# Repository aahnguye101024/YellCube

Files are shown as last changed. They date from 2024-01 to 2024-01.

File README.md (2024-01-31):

# YellCube
This device is intended to connect stream audio and flash lights representative of the audio. This device streams songs that are uploaded to another repo (https://github.com/aahnguye101024/ESP32Audio). This project was also a way for me to test out the 3D printer I just bought in a fun way. With an ESP32 pico d4 with an antenna, onboard leds, a dedicated SK6812 LED board, an audio amplifier, an onboard lipo with supported charging and uploading straight to the pico D4, this board can be easily programmed and adapted to any of your speaker and lights project needs.

# Main Board
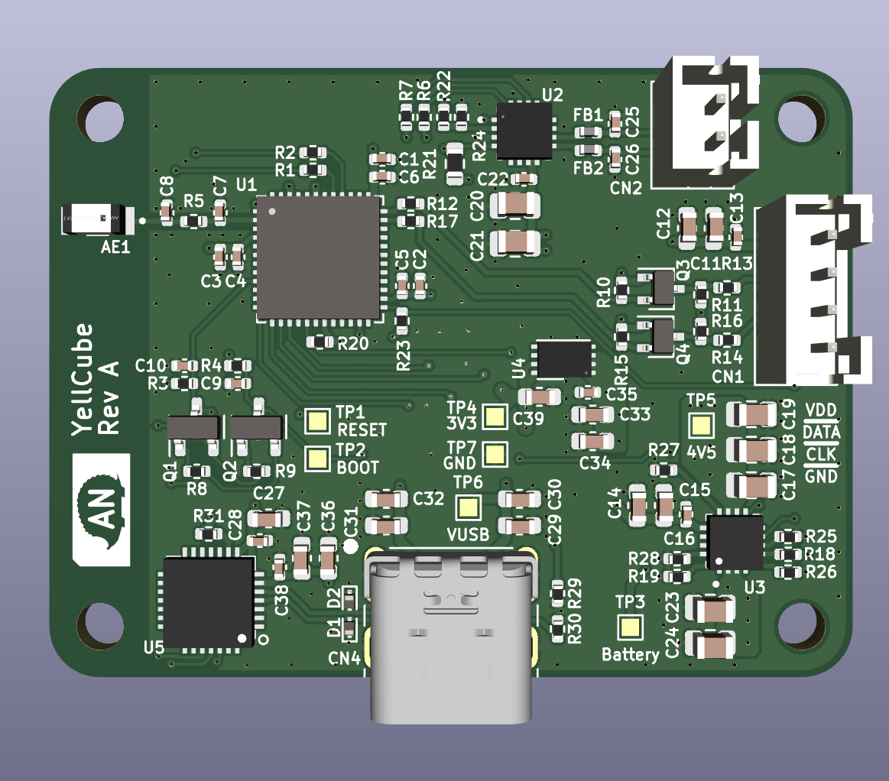
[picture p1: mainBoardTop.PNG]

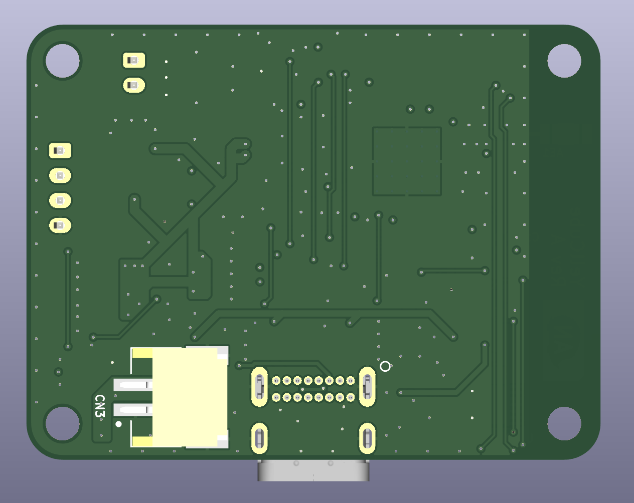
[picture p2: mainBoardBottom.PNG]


# Lights Board
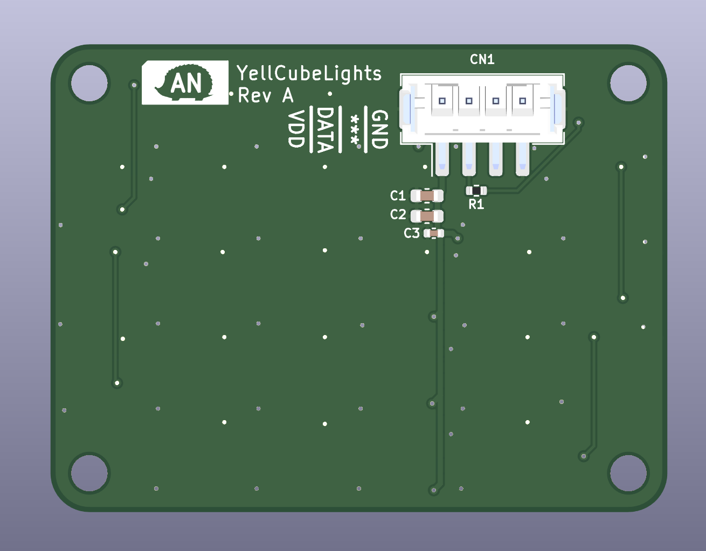
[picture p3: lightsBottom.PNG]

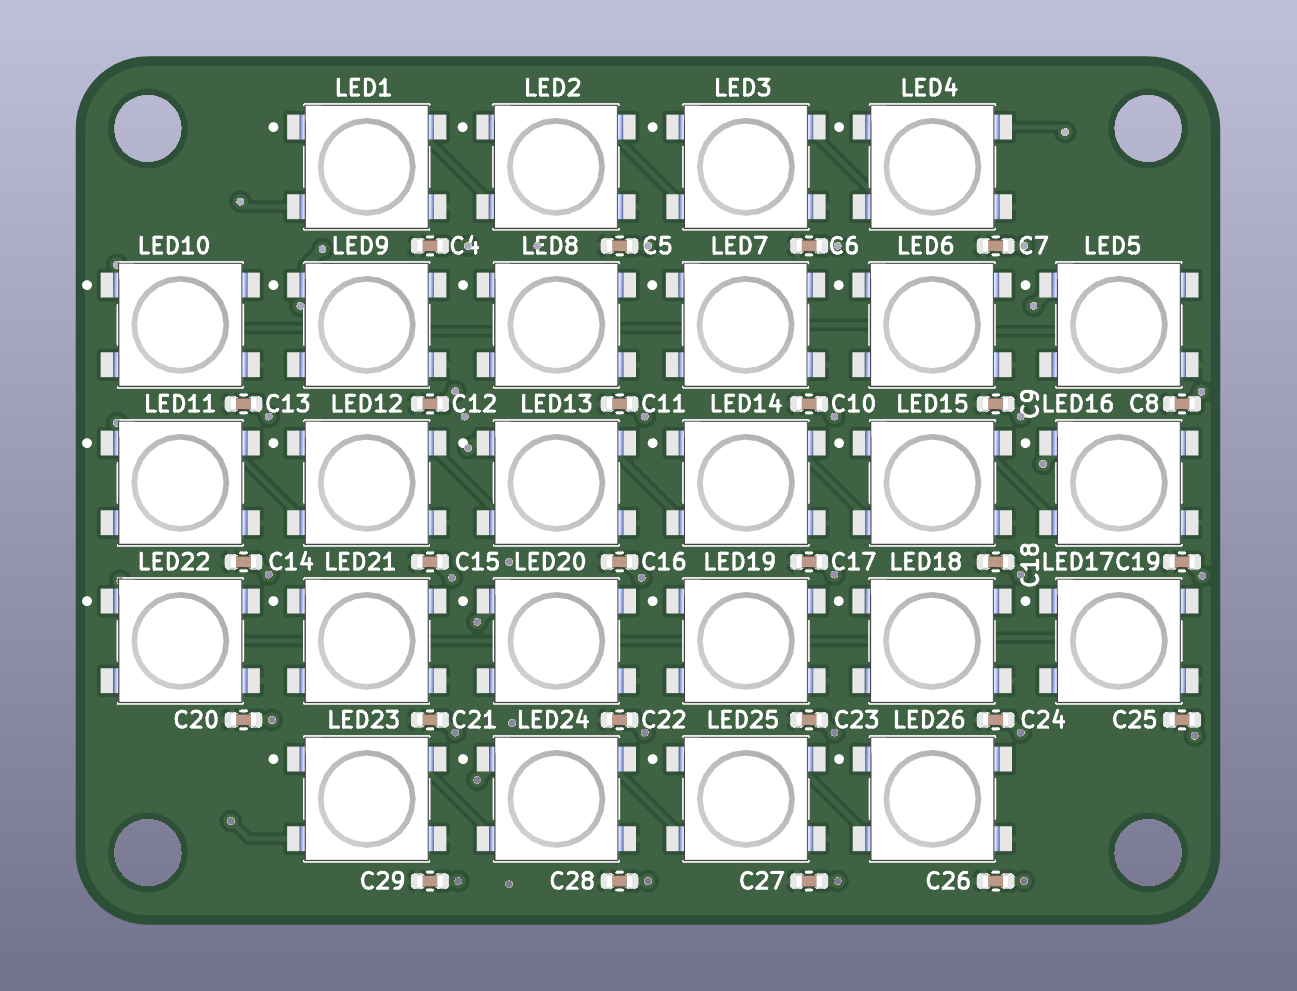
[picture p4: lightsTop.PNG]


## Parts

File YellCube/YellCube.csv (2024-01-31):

Source: | C:\Users\AaronN\Desktop\Personal\PersonalProjects\YellCube\YellCube\YellCube.kicad_sch
Date: | 4/16/2022 9:40:53 PM
Tool: | Eeschema (6.0.0)
Generator: | C:\Program Files\KiCad\bin\scripting\plugins/AaronsFavoriteBOMScript.py
Component Count: | 90
Ref | Qnty | Value | Cmp name | Description | Manufacturer | Part Number
AE1, | 1 | AMCA31-2R450G-S1F-T3 | AMCA31-2R450G-S1F-T3 | RF ANT 2.4GHZ CHIP SOLDER SMD | Personal | 535-14095-1-ND
C1, C2, C3, C10, | 4 | 1uF | 1uF | CAP CER 1UF 10V X5R 0402 | Samsung Electro-Mechanics | 1276-1076-1-ND
C4, C5, C6, C9, C13, C16, C22, C28, C35, C38, | 10 | 0.1uF | 0.1uF | CAP CER 0.1UF 25V X5R 0402 | Samsung Electro-Mechanics | 1276-1043-1-ND
C11, C12, C33, C34, C39, | 5 | 4.7uF | 4.7uF | CAP CER 4.7UF 16V X5R 0603 | Samsung Electro-Mechanics | 1276-1784-1-ND
C14, C15, C27, C29, C30, C31, C32, C36, C37, | 9 | 2.2uF | 2.2uF | CAP CER 2.2UF 10V X5R 0603 | Samsung Electro-Mechanics | 1276-1085-1-ND
C17, C18, C19, C20, C21, C23, C24, | 7 | 10uF | 10uF | CAP CER 10UF 16V X5R 0805 | Samsung Electro-Mechanics | 1276-2893-1-ND
C25, C26, | 2 | 220pF | 220pF | CAP CER 220PF 50V X7R 0402 | YAGEO | 311-1035-1-ND
CN1, | 1 | B4B-PH-K-S(LF)(SN) | B4B-PH-K-S(LF)(SN) | JST PH CONN HEADER VERT 4POS 2MM | JST Sales America Inc. | 455-1706-ND
CN2, | 1 | B2B-PH-K-S(LF)(SN) | B2B-PH-K-S(LF)(SN) | JST PH CONN HEADER VERT 2POS 2MM | JST Sales America Inc. | 455-1704-ND
CN3, | 1 | S2B-PH-SM4-TB(LF)(SN) | S2B-PH-SM4-TB(LF)(SN) | JST PH R/A CONN HEADER SMD R/A 2POS 2MM | JST Sales America Inc. | 455-1749-1-ND
CN4, | 1 | 2137160001 | 2137160001 | CONN RCPT USB2.0 TYPE C 24POS RA | Personal | 900-2137160001CT-ND
D1, D2, | 2 | ESD7951ST5G | ESD7951ST5G | TVS DIODE 5VWM 12.9VC SOD923 | onsemi | ESD7951ST5GOSCT-ND
FB1, FB2, | 2 | BLM15PX601SN1D | BLM15PX601SN1D | FERRITE BEAD 600 OHM 0402 1LN | Murata Electronics | 490-9657-1-ND
H1, H2, H3, H4, | 4 | MountingHole | MountingHole | Mounting Hole without connection
Q1, Q2, | 2 | MMBT3904 | MMBT3904 | JLCPCB 0.2W 0.2A NPN 40V SOT-23(SOT-23-3) Bipolar Transistors - BJT ROHS | Changjiang Electronics Tech (CJ) | C20526
Q3, Q4, | 2 | BSS138W-7-F | BSS138W-7-F | 50V Vds, 0.2A Id, N-Channel MOSFET, SOT-323 | Personal | BSS138W-FDICT-ND
R1, R2, R5, R12, R13, R14, R17, | 7 | 0 | 0 | RES 0 OHM JUMPER 1/16W 0402 | Stackpole Electronics Inc | RMCF0402ZT0R00CT-ND
R3, R8, R9, R10, R11, R15, R16, R18, R19, R20, R23, R25, R26, R31, | 14 | 10k | 10k | RES 10K OHM 1% 1/16W 0402 | Stackpole Electronics Inc | RMCF0402FT10K0CT-ND
R4, R28, | 2 | 4.7k | 4.7k | RES 4.7K OHM 1% 1/16W 0402 | Stackpole Electronics Inc | RMCF0402FT4K70CT-ND
R6, R7, | 2 | 33 | 33 | RES 33 OHM 1% 1/16W 0402 | YAGEO | 311-33.0LRCT-ND
R21, | 1 | 680k | 680k | RES 680K OHM 1% 1/10W 0603 | Stackpole Electronics Inc | RMCF0603FT680KCT-ND
R22, R24, | 2 | 100k | 100k | RES SMD 100 KOHM 1% 1/16W 0402 | Delta Electronics/Cyntec | 2037-PFR05S-104-FNHCT-ND
R27, | 1 | 3.09k | 3.09k | RES 3.09K OHM 1% 1/16W 0402 | Stackpole Electronics Inc | RMCF0402FT3K09CT-ND
R29, R30, | 2 | 5.1k | 5.1k | RES 5.1K OHM 1% 1/16W 0402 | YAGEO | 311-5.10KLRCT-ND
U1, | 1 | ESP32-PICO-D4 | ESP32-PICO-D4 |  | Personal | 1904-1029-1-ND
U2, | 1 | MAX98357AETE+T | MAX98357AETE+T | JLCPCB IC AMP CLASS D MONO 3.2W 16TQFN | Analog Devices Inc./Maxim Integrated | MAX98357AETE+TCT-ND
U3, | 1 | BQ24232HARGTR | BQ24232HARGTR | IC BATT CHG LI-ION 1CELL 16QFN | Texas Instruments | 296-49554-1-ND
U4, | 1 | MCP1725T-3302E/MC | MCP1725T-3302E{slash}MC | IC REG LINEAR 3.3V 500MA 8DFN | Microchip Technology | MCP1725T-3302E/MCCT-ND
U5, | 1 | CP2102-GMR | CP2102-GMR | JLCPCB IC USB-TO-UART BRIDGE 28VQFN | Personal | IC USB-TO-UART BRIDGE 28VQFN

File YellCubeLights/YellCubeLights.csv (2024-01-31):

Source: | C:\Users\AaronN\Desktop\Personal\PersonalProjects\YellCube\YellCubeLights\YellCubeLights.kicad_sch
Date: | 4/16/2022 9:31:28 PM
Tool: | Eeschema (6.0.0)
Generator: | C:\Program Files\KiCad\bin\scripting\plugins/AaronsFavoriteBOMScript.py
Component Count: | 61
Ref | Qnty | Value | Cmp name | Description | Manufacturer | Part Number
C1, C2, | 2 | 2.2uF | 2.2uF | CAP CER 2.2UF 10V X5R 0603 | Samsung Electro-Mechanics | 1276-1085-1-ND
C3, | 1 | 0.1uF | 0.1uF | CAP CER 0.1UF 25V X5R 0402 | Samsung Electro-Mechanics | 1276-1043-1-ND
C4, C5, C6, C7, C8, C9, C10, C11, C12, C13, C14, C15, C16, C17, C18, C19, C20, C21, C22, C23, C24, C25, C26, C27, C28, C29, | 26 | 1uF | 1uF | CAP CER 1UF 10V X5R 0402 | Samsung Electro-Mechanics | 1276-1076-1-ND
CN1, | 1 | B4B-PH-SM4-TBT(LF)(SN) | B4B-PH-SM4-TBT(LF)(SN) | JST PH CONN HEADER SMD 4POS 2MM | JST Sales America Inc. | 455-2873-1-ND
H1, H2, H3, H4, | 4 | MountingHole | MountingHole | Mounting Hole without connection
LED1, LED2, LED3, LED4, LED5, LED6, LED7, LED8, LED9, LED10, LED11, LED12, LED13, LED14, LED15, LED16, LED17, LED18, LED19, LED20, LED21, LED22, LED23, LED24, LED25, LED26, | 26 | SK6812 | SK6812 | RGBW LED | Pololu | N/A
R1, | 1 | 33 | 33 | RES 33 OHM 1% 1/16W 0402 | YAGEO | 311-33.0LRCT-ND

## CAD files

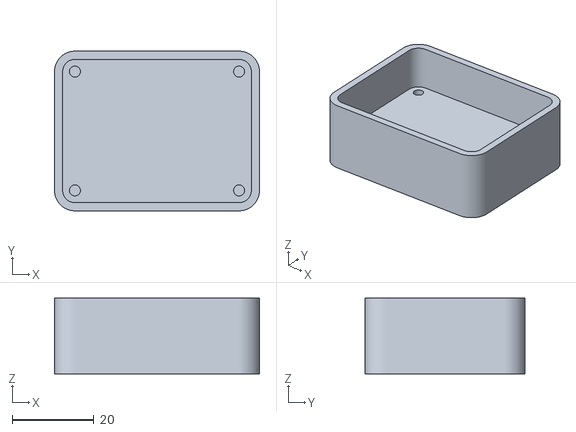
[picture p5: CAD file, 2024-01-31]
mechanical/stl/BottomCase v3.stl
50.2 x 39.1 x 18.6

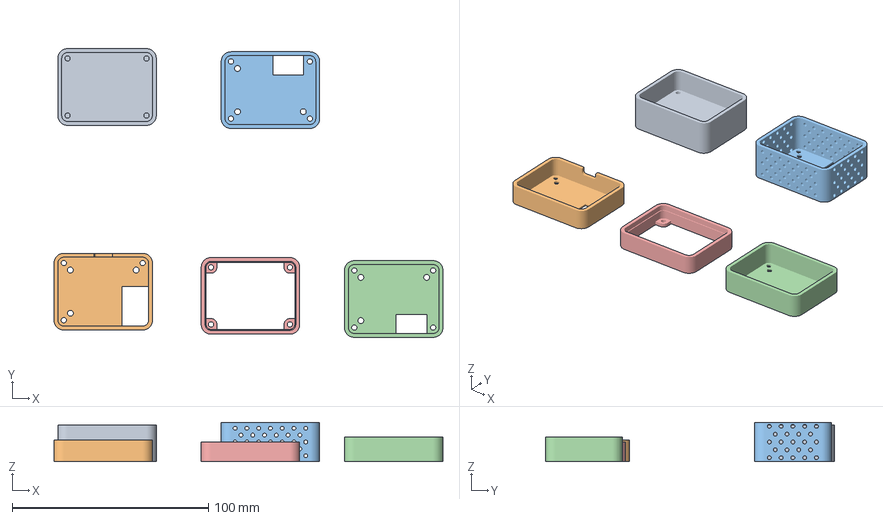
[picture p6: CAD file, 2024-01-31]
mechanical/YellCube.3mf
198.2 x 147.1 x 20.0 mm
BottomCase v3.stl
MidCase v5.stl
MiddleSpeakerWall v3.stl
Top v2.stl
TippyTop v2.stl

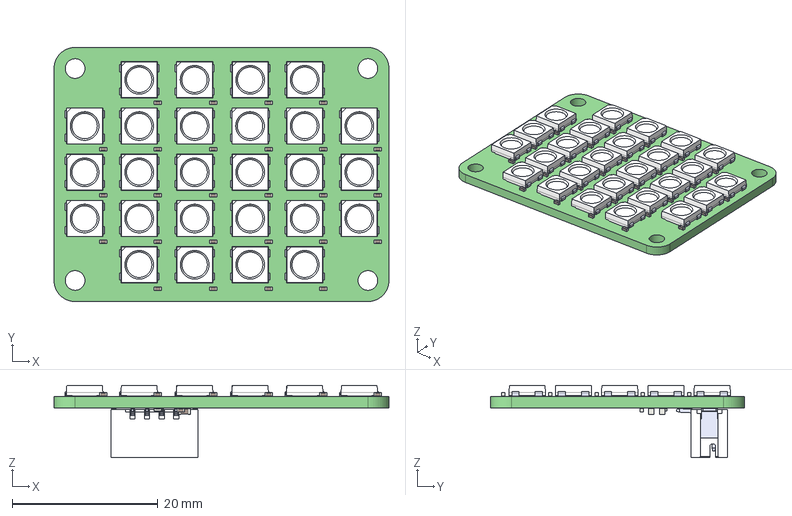
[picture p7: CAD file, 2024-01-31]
YellCubeLights/YellCubeLights.step
46.0 x 34.9 x 9.95 mm
YellCubeLights PCB

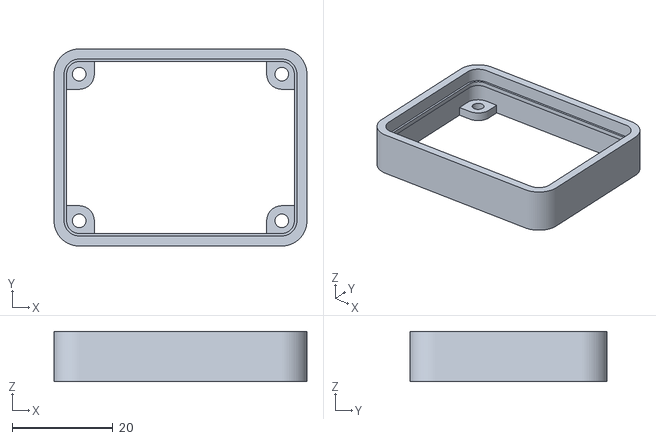
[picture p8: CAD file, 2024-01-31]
mechanical/stl/TippyTop v2.stl
50.2 x 39.1 x 10.0

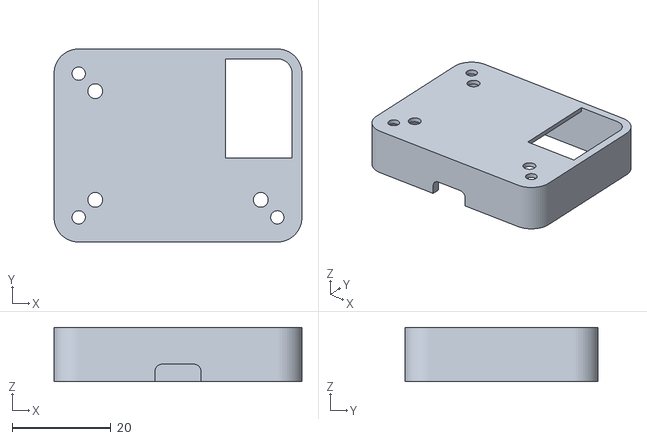
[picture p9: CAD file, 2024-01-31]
mechanical/stl/MidCase v5.stl
50.2 x 39.1 x 11.0

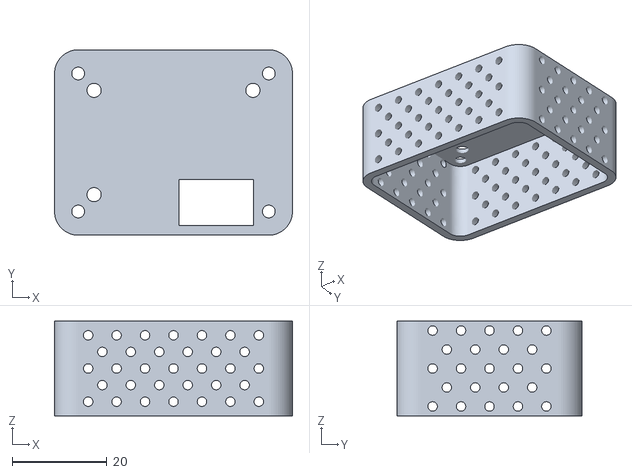
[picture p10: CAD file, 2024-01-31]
mechanical/stl/MiddleSpeakerWall v3.stl
50.2 x 39.1 x 20.0

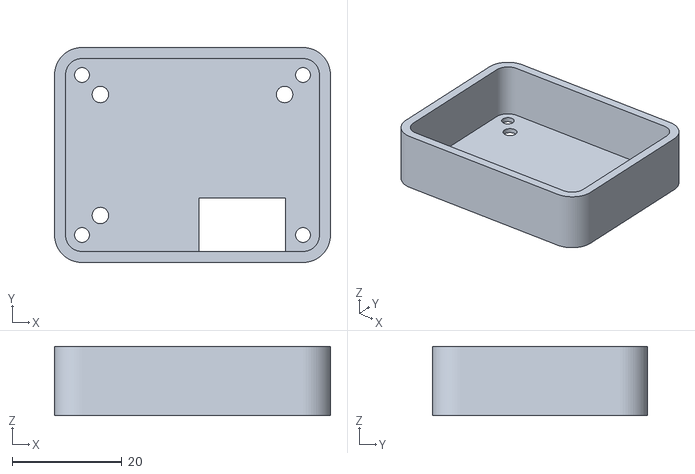
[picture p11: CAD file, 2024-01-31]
mechanical/stl/Top v2.stl
50.2 x 39.1 x 12.6

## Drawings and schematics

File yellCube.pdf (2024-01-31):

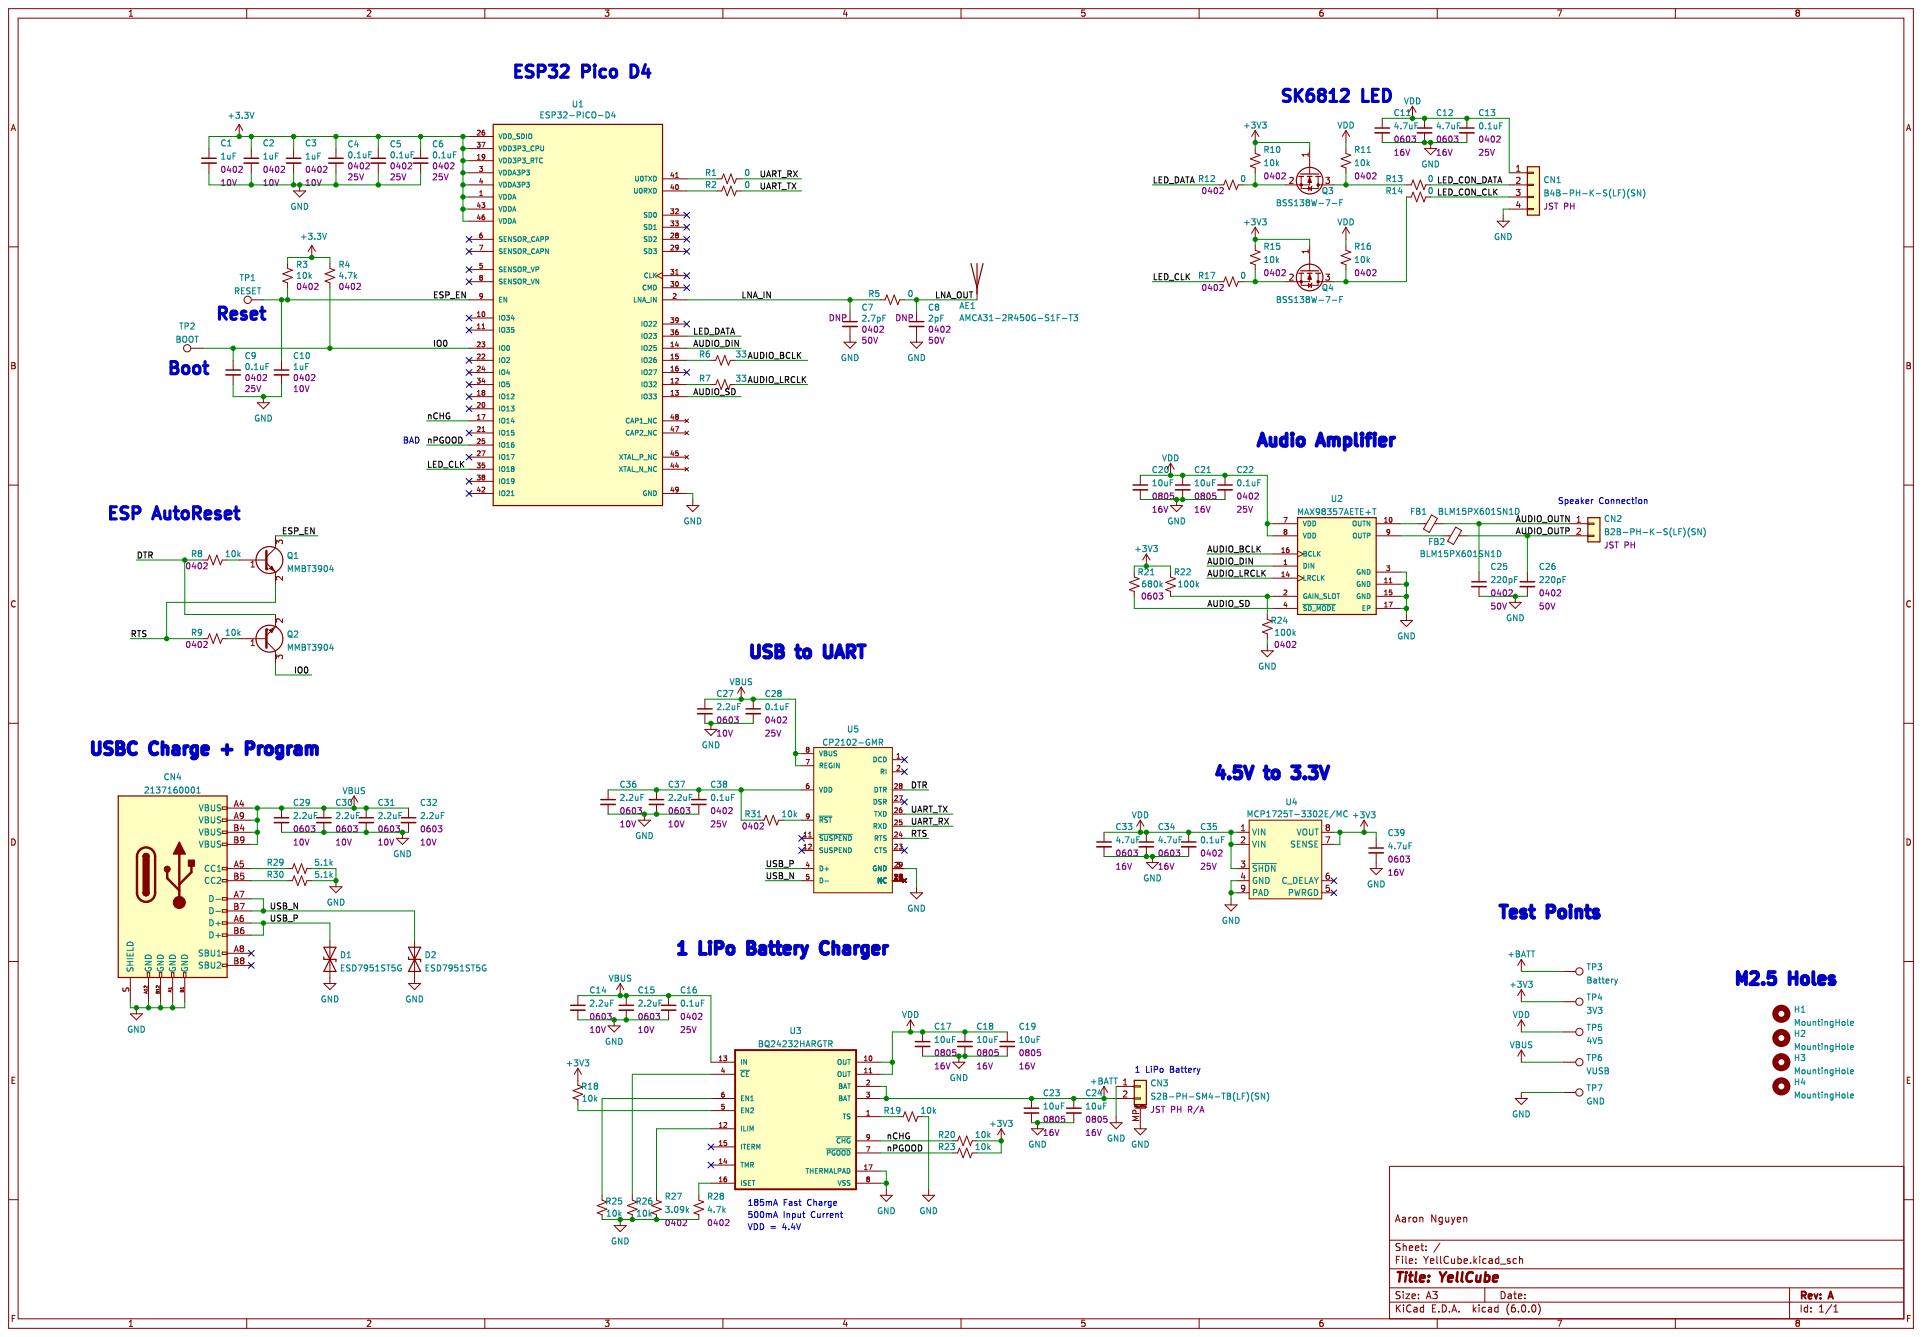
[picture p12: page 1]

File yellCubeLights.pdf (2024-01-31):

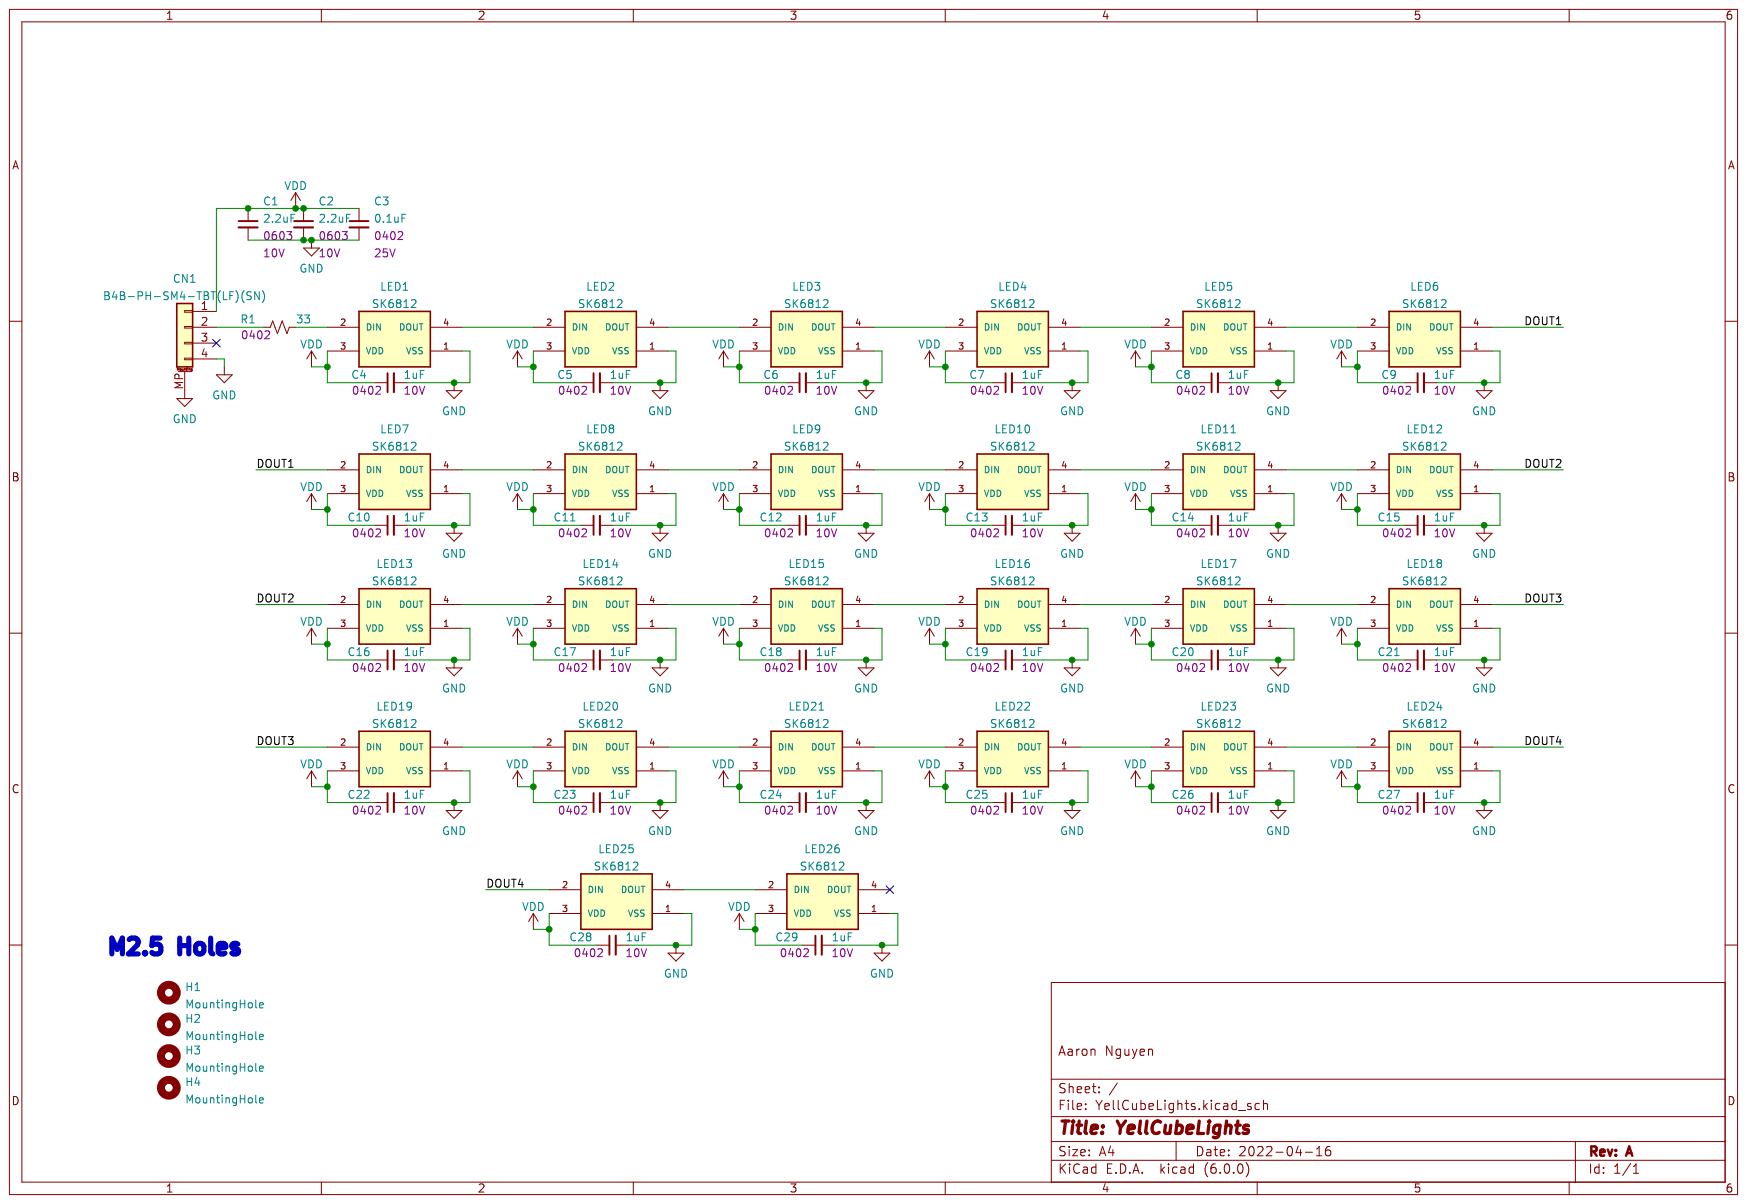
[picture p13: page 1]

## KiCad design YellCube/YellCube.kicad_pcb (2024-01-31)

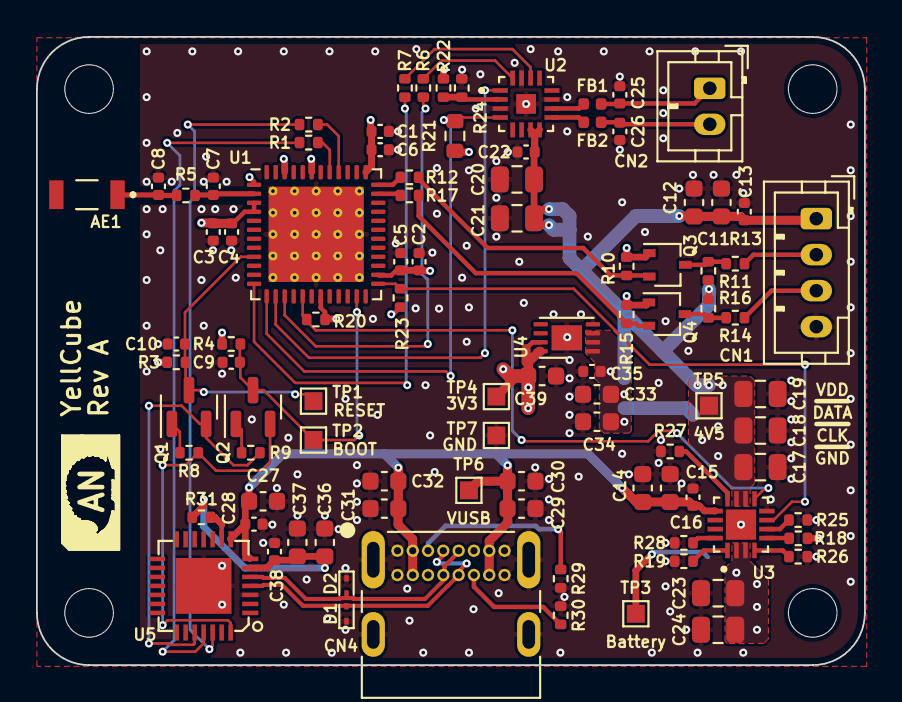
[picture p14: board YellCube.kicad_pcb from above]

Board: 4 copper layers, 46.0 x 34.9 mm, 99 parts (1 on the bottom side), 50 nets.

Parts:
AE1: AMCA31-2R450G-S1F-T3; ANT_AMCA31-2R450G-S1F-T3
C1, C2, C3, C10: 1uF; C_0402_1005Metric
C4, C5, C6, C9, C13, C16, C22, C28, C35, C38: 0.1uF; C_0402_1005Metric
C7: 2.7pF; C_0402_1005Metric
C8: 2pF; C_0402_1005Metric
C11, C12, C33, C34, C39: 4.7uF; C_0603_1608Metric
C14, C15, C27, C29, C30, C31, C32, C36, C37: 2.2uF; C_0603_1608Metric
C17, C18, C19, C20, C21, C23, C24: 10uF; C_0805_2012Metric
C25, C26: 220pF; C_0402_1005Metric
CN1: B4B-PH-K-S(LF)(SN); JST_PH_B4B-PH-K_1x04_P2.00mm_Vertical
CN2: B2B-PH-K-S(LF)(SN); JST_PH_B2B-PH-K_1x02_P2.00mm_Vertical
CN3: S2B-PH-SM4-TB(LF)(SN); JST_S2B-PH-SM4-TB(LF)(SN)
CN4: 2137160001
D1, D2: ESD7951ST5G; D_SOD-923
FB1, FB2: BLM15PX601SN1D; L_0402_1005Metric
H1, H2, H3, H4: MountingHole; MountingHole_2.7mm_M2.5_ISO14580
Q1, Q2: MMBT3904; SOT-23
Q3, Q4: BSS138W-7-F; SOT-323_SC-70
R1, R2, R5, R12, R13, R14, R17: 0; R_0402_1005Metric
R3, R8, R9, R10, R11, R15, R16, R18, R19, R20, R23, R25, R26, R31: 10k; R_0402_1005Metric
R4, R28: 4.7k; R_0402_1005Metric
R6, R7: 33; R_0402_1005Metric
R21: 680k; R_0603_1608Metric
R22, R24: 100k; R_0402_1005Metric
R27: 3.09k; R_0402_1005Metric
R29, R30: 5.1k; R_0402_1005Metric
TP1: RESET; CurrentTestPoint
TP2: BOOT; CurrentTestPoint
TP3: Battery; CurrentTestPoint
TP4: 3V3; CurrentTestPoint
TP5: 4V5; CurrentTestPoint
TP6: VUSB; CurrentTestPoint
TP7: GND; CurrentTestPoint
U1: ESP32-PICO-D4; QFN-48-1EP_7x7mm_P0.5mm_EP5.3x5.3mm_ThermalVias
U2: MAX98357AETE+T; QFN50P300X300X80-17N
U3: BQ24232HARGTR; QFN50P300X300X100-17N
U4: MCP1725T-3302E/MC; MCP1725T-3302E
U5: CP2102-GMR; QFN28G_0.5-5X5MM

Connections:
+3V3: C1.1, C2.1, C3.1, C4.1, C5.1, C6.1, C39.1, Q3.1 (G), Q4.1 (G), R3.1, R4.1, R10.1, R15.1, R18.1, R20.2, R21.1, R22.2, R23.2, TP4.1, U1.1 (VDDA), U1.3 (VDDA3P3), U1.4 (VDDA3P3), U1.19 (VDD3P3_RTC), U1.26 (VDD_SDIO), U1.37 (VDD3P3_CPU), U1.43 (VDDA), U1.46 (VDDA), U4.7 (SENSE), U4.8 (VOUT)
+BATT: C23.1, C24.1, CN3.2, TP3.1, U3.2 (BAT), U3.3 (BAT)
/AUDIO_BCLK: R6.2, U2.16 (BCLK)
/AUDIO_DIN: U1.14 (IO25), U2.1 (DIN)
/AUDIO_LRCLK: R7.2, U2.14 (LRCLK)
/AUDIO_OUTN: C25.1, CN2.1, FB1.2
/AUDIO_OUTP: C26.1, CN2.2, FB2.2
/AUDIO_SD: R21.2, U1.13 (IO33), U2.4 (~SD_MODE)
/DTR: Q2.2 (E), R8.2, U5.28 (DTR)
/ESP_EN: C10.1, Q1.3 (C), R3.2, TP1.1, U1.9 (EN)
/IO0: C9.1, Q2.3 (C), R4.2, TP2.1, U1.23 (IO0)
/LED_CLK: R17.1, U1.35 (IO18)
/LED_CON_CLK: CN1.3, R14.2
/LED_CON_DATA: CN1.2, R13.2
/LED_DATA: R12.1, U1.36 (IO23)
/LNA_IN: C7.1, R5.2, U1.2 (LNA_IN)
/LNA_OUT: AE1.1 (A), C8.1, R5.1
/RTS: Q1.2 (E), R9.2, U5.24 (RTS)
/UART_RX: R1.1, U5.25 (RXD)
/UART_TX: R2.1, U5.26 (TXD)
/USB_N: CN4.A7 (D-), CN4.B7 (D-), D2.2 (A2), U5.5 (D-)
/USB_P: CN4.A6 (D+), CN4.B6 (D+), D1.2 (A2), U5.4 (D+)
/nCHG: R20.1, U1.17 (IO14), U3.9 (~CHG)
/nPGOOD: R23.1, U1.25 (IO16), U3.7 (~PGOOD)
GND: C1.2, C2.2, C3.2, C4.2, C5.2, C6.2, C7.2, C8.2, C9.2, C10.2, C11.2, C12.2, C13.2, C14.2, C15.2, C16.2, C17.2, C18.2, C19.2, C20.2, C21.2, C22.2, C23.2, C24.2, C25.2, C26.2, C27.2, C28.2, C29.2, C30.2, C31.2, C32.2, C33.2, C34.2, C35.2, C36.2, C37.2, C38.2, C39.2, CN1.4, CN3.1, CN3.MP (MountPin), CN4.A1 (GND), CN4.A12 (GND), CN4.B1 (GND), CN4.B12 (GND), CN4.S (SHIELD), D1.1 (A1), D2.1 (A1), R19.2, R24.1, R25.2, R26.2, R27.2, R28.2, R29.2, R30.2, TP7.1, U1.49 (GND), U2.3 (GND), U2.11 (GND), U2.15 (GND), U2.17 (EP), U3.8 (VSS), U3.17 (THERMALPAD), U4.4 (GND), U4.9 (PAD), U5.3 (GND), U5.29 (GND)
unnamed: C36.1, C37.1, C38.1, R31.1, U5.6 (VDD)
unnamed: CN4.A5 (CC1), R29.1
unnamed: CN4.B5 (CC2), R30.1
unnamed: FB1.1, U2.10 (OUTN)
unnamed: FB2.1, U2.9 (OUTP)
unnamed: Q1.1 (B), R8.1
unnamed: Q2.1 (B), R9.1
unnamed: Q3.2 (S), R10.2, R12.2
unnamed: Q3.3 (D), R11.2, R13.1
unnamed: Q4.2 (S), R15.2, R17.2
unnamed: Q4.3 (D), R14.1, R16.2
unnamed: R1.2, U1.41 (U0TXD)
unnamed: R2.2, U1.40 (U0RXD)
unnamed: R6.1, U1.15 (IO26)
unnamed: R7.1, U1.12 (IO32)
unnamed: R18.2, U3.5 (EN2)
unnamed: R19.1, U3.1 (TS)
unnamed: R22.1, R24.2, U2.2 (GAIN_SLOT)
unnamed: R25.1, U3.6 (EN1)
unnamed: R26.1, U3.4 (~CE)
unnamed: R27.1, U3.12 (ILIM)
unnamed: R28.1, U3.16 (ISET)
unnamed: R31.2, U5.9 (~RST)
VBUS: C14.1, C15.1, C16.1, C27.1, C28.1, C29.1, C30.1, C31.1, C32.1, CN4.A4 (VBUS), CN4.A9 (VBUS), CN4.B4 (VBUS), CN4.B9 (VBUS), TP6.1, U3.13 (IN), U5.7 (REGIN), U5.8 (VBUS)
VDD: C11.1, C12.1, C13.1, C17.1, C18.1, C19.1, C20.1, C21.1, C22.1, C33.1, C34.1, C35.1, CN1.1, R11.1, R16.1, TP5.1, U2.7 (VDD), U2.8 (VDD), U3.10 (OUT), U3.11 (OUT), U4.1 (VIN), U4.2 (VIN), U4.3 (~SHDN)

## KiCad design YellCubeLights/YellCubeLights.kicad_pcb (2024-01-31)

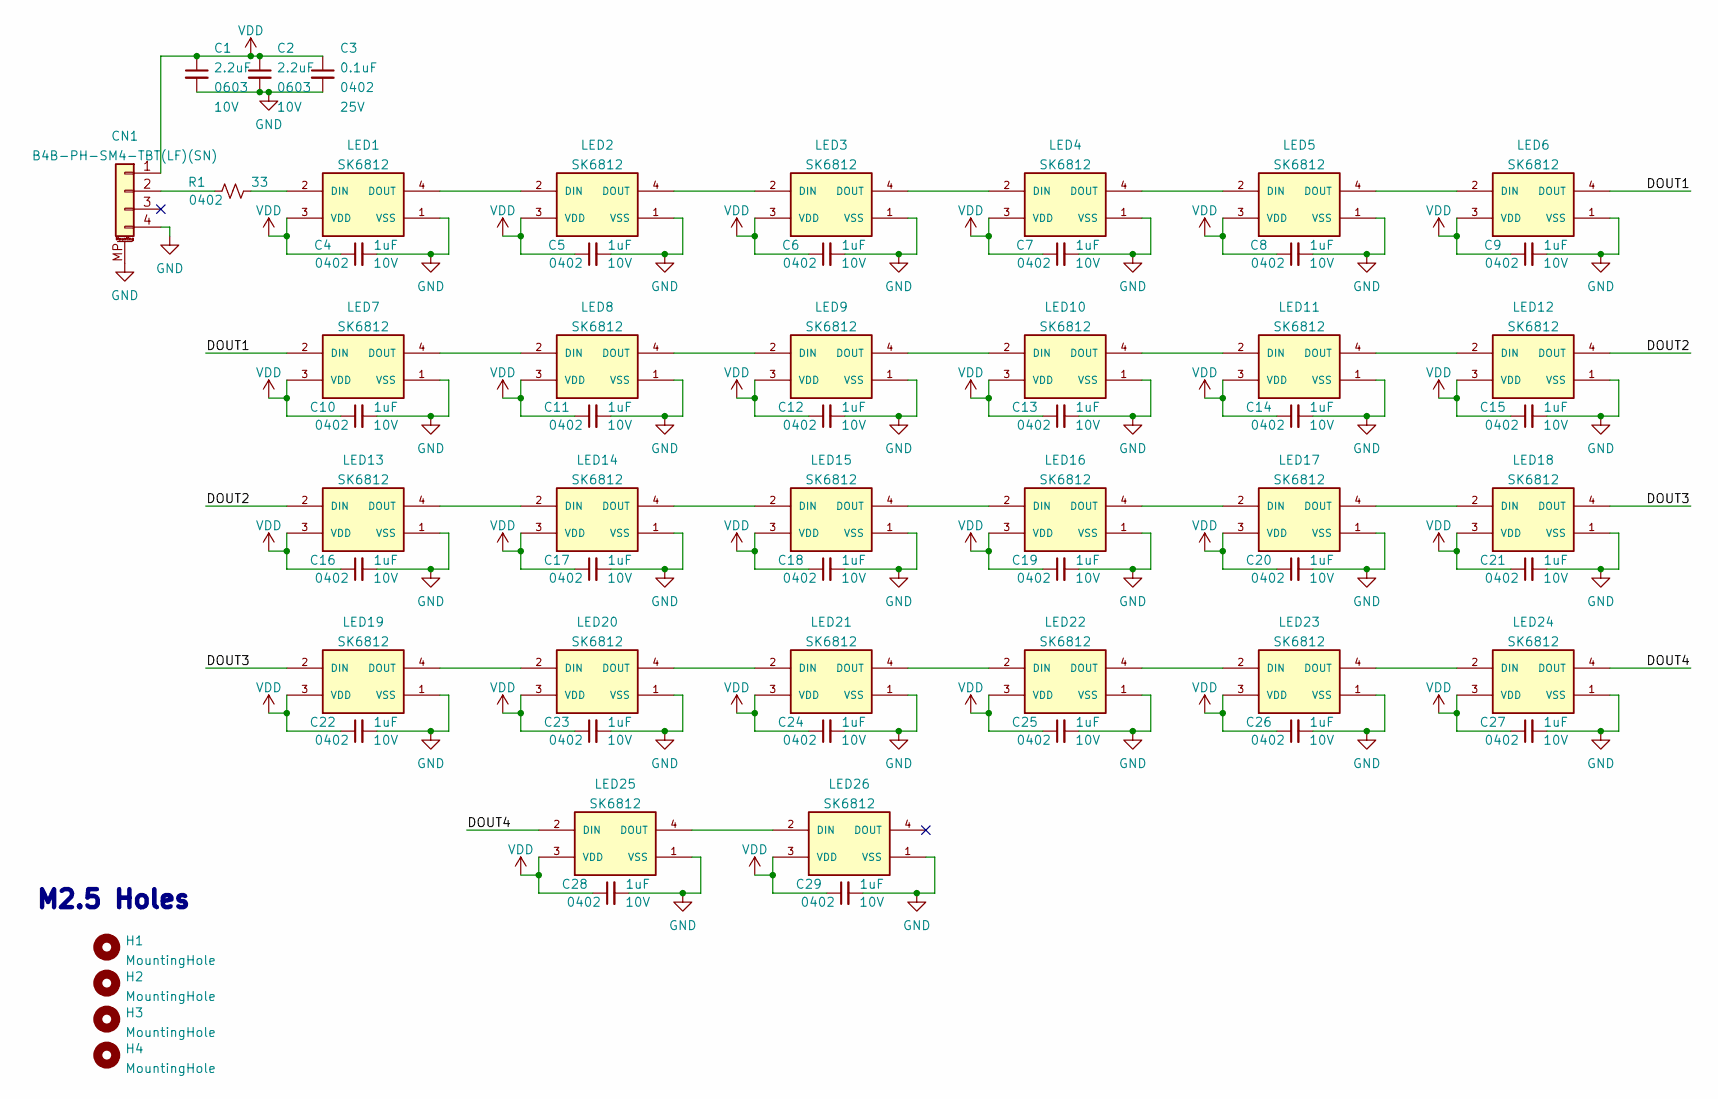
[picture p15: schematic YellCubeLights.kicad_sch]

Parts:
C1, C2: 2.2uF; C_0603_1608Metric; Voltage 10V; Part Number 1276-1085-1-ND
C3: 0.1uF; C_0402_1005Metric; Voltage 25V; Part Number 1276-1043-1-ND
C4, C5, C6, C7, C8, C9, C10, C11, C12, C13, C14, C15, C16, C17, C18, C19, C20, C21, C22, C23, C24, C25, C26, C27, C28, C29: 1uF; C_0402_1005Metric; Voltage 10V; Part Number 1276-1076-1-ND
CN1: B4B-PH-SM4-TBT(LF)(SN); Part Number 455-2873-1-ND
H1, H2, H3, H4: MountingHole; MountingHole_2.7mm_M2.5_ISO14580
LED1, LED2, LED3, LED4, LED5, LED6, LED7, LED8, LED9, LED10, LED11, LED12, LED13, LED14, LED15, LED16, LED17, LED18, LED19, LED20, LED21, LED22, LED23, LED24, LED25, LED26: SK6812; Part Number N/A
R1: 33; R_0402_1005Metric; Part Number 311-33.0LRCT-ND

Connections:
/DOUT1: LED6.4 (DOUT), LED7.2 (DIN)
/DOUT2: LED12.4 (DOUT), LED13.2 (DIN)
/DOUT3: LED18.4 (DOUT), LED19.2 (DIN)
/DOUT4: LED24.4 (DOUT), LED25.2 (DIN)
GND: C1.2, C2.2, C3.2, C4.2, C5.2, C6.2, C7.2, C8.2, C9.2, C10.2, C11.2, C12.2, C13.2, C14.2, C15.2, C16.2, C17.2, C18.2, C19.2, C20.2, C21.2, C22.2, C23.2, C24.2, C25.2, C26.2, C27.2, C28.2, C29.2, CN1.4, CN1.MP (MountPin), LED1.1 (VSS), LED2.1 (VSS), LED3.1 (VSS), LED4.1 (VSS), LED5.1 (VSS), LED6.1 (VSS), LED7.1 (VSS), LED8.1 (VSS), LED9.1 (VSS), LED10.1 (VSS), LED11.1 (VSS), LED12.1 (VSS), LED13.1 (VSS), LED14.1 (VSS), LED15.1 (VSS), LED16.1 (VSS), LED17.1 (VSS), LED18.1 (VSS), LED19.1 (VSS), LED20.1 (VSS), LED21.1 (VSS), LED22.1 (VSS), LED23.1 (VSS), LED24.1 (VSS), LED25.1 (VSS), LED26.1 (VSS)
unnamed: LED1.2 (DIN), R1.2
unnamed: LED1.4 (DOUT), LED2.2 (DIN)
unnamed: LED2.4 (DOUT), LED3.2 (DIN)
unnamed: LED3.4 (DOUT), LED4.2 (DIN)
unnamed: LED4.4 (DOUT), LED5.2 (DIN)
unnamed: LED5.4 (DOUT), LED6.2 (DIN)
unnamed: LED7.4 (DOUT), LED8.2 (DIN)
unnamed: LED8.4 (DOUT), LED9.2 (DIN)
unnamed: LED9.4 (DOUT), LED10.2 (DIN)
unnamed: LED10.4 (DOUT), LED11.2 (DIN)
unnamed: LED11.4 (DOUT), LED12.2 (DIN)
unnamed: LED13.4 (DOUT), LED14.2 (DIN)
unnamed: LED14.4 (DOUT), LED15.2 (DIN)
unnamed: LED15.4 (DOUT), LED16.2 (DIN)
unnamed: LED16.4 (DOUT), LED17.2 (DIN)
unnamed: LED17.4 (DOUT), LED18.2 (DIN)
unnamed: LED19.4 (DOUT), LED20.2 (DIN)
unnamed: LED20.4 (DOUT), LED21.2 (DIN)
unnamed: LED21.4 (DOUT), LED22.2 (DIN)
unnamed: LED22.4 (DOUT), LED23.2 (DIN)
unnamed: LED23.4 (DOUT), LED24.2 (DIN)
unnamed: LED25.4 (DOUT), LED26.2 (DIN)
unnamed: CN1.2, R1.1
VDD: C1.1, C2.1, C3.1, C4.1, C5.1, C6.1, C7.1, C8.1, C9.1, C10.1, C11.1, C12.1, C13.1, C14.1, C15.1, C16.1, C17.1, C18.1, C19.1, C20.1, C21.1, C22.1, C23.1, C24.1, C25.1, C26.1, C27.1, C28.1, C29.1, CN1.1, LED1.3 (VDD), LED2.3 (VDD), LED3.3 (VDD), LED4.3 (VDD), LED5.3 (VDD), LED6.3 (VDD), LED7.3 (VDD), LED8.3 (VDD), LED9.3 (VDD), LED10.3 (VDD), LED11.3 (VDD), LED12.3 (VDD), LED13.3 (VDD), LED14.3 (VDD), LED15.3 (VDD), LED16.3 (VDD), LED17.3 (VDD), LED18.3 (VDD), LED19.3 (VDD), LED20.3 (VDD), LED21.3 (VDD), LED22.3 (VDD), LED23.3 (VDD), LED24.3 (VDD), LED25.3 (VDD), LED26.3 (VDD)

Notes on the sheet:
M2.5 Holes

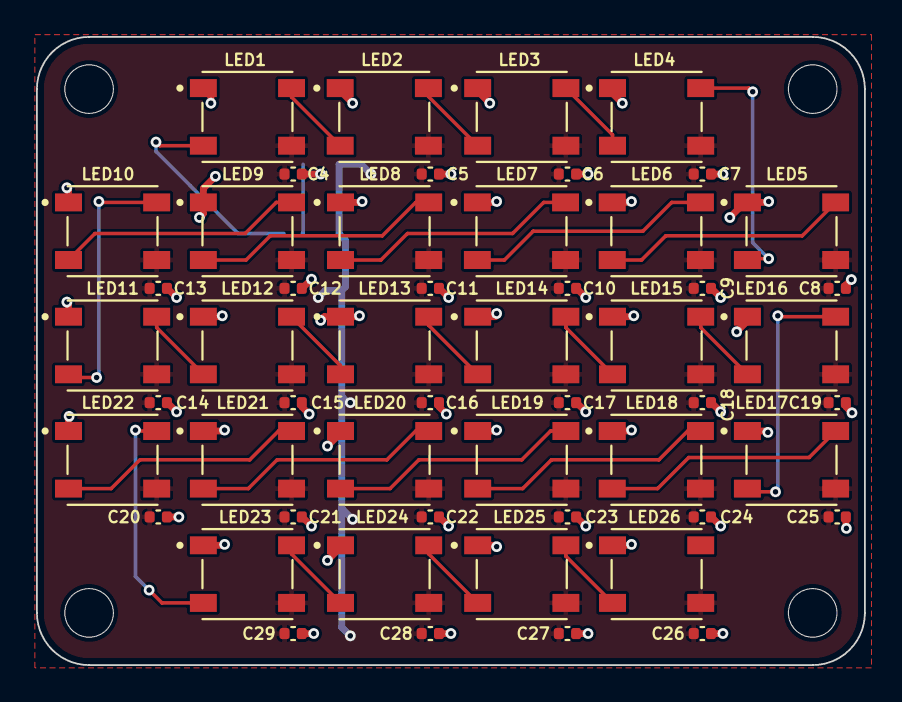
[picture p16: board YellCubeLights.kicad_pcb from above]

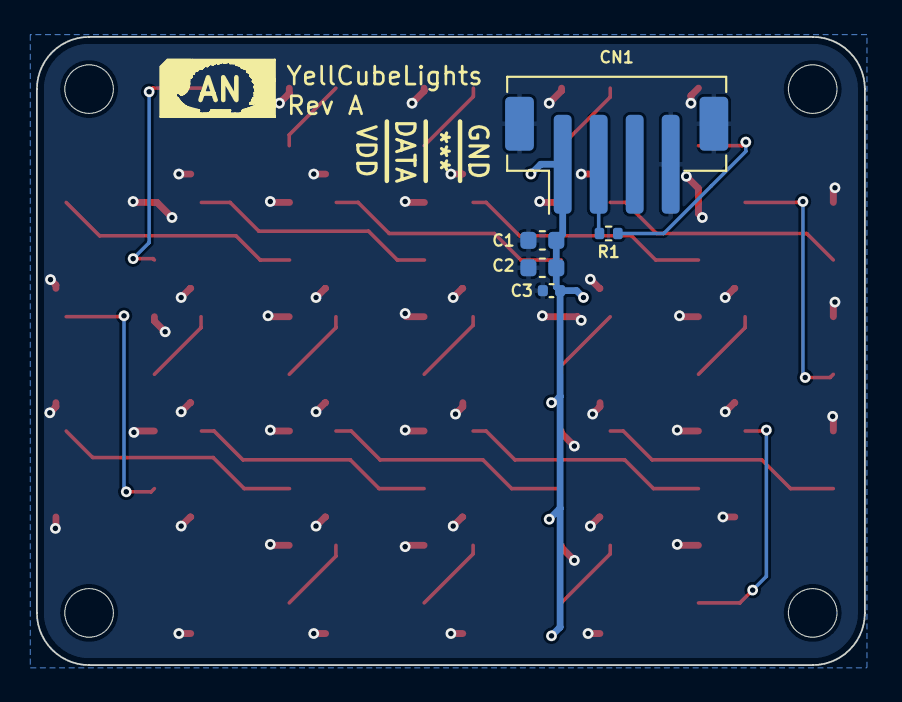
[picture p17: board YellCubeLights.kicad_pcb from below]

Board: 2 copper layers, 46.0 x 34.9 mm, 61 parts (5 on the bottom side), 29 nets.
